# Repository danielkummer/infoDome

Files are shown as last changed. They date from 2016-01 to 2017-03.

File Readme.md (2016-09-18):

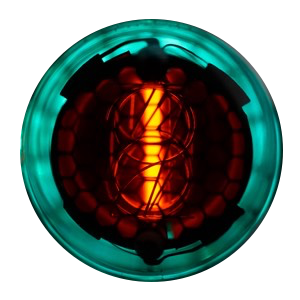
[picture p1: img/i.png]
I


# InfoDome

InfoDome Demo (http://www.youtube.com/watch?v=v8ImjMalxpY)

## Introduction

The InfoDome is an IoT project using an Arduino yùn to fetch and display remote information as well as temperature and RTC data through four [QS30-1](https://www.google.ch/search?q=QS30-1) nixie tubes.

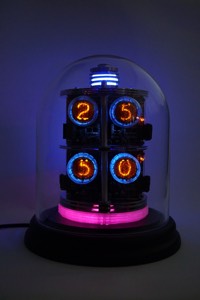
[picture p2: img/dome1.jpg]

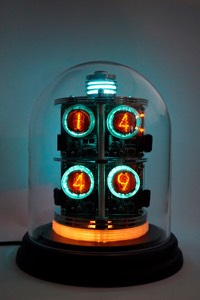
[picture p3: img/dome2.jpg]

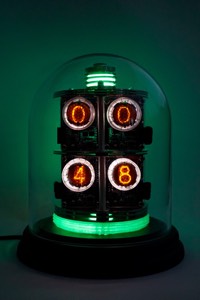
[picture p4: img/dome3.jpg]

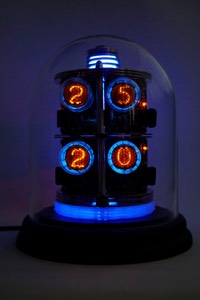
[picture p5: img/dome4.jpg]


## Features

- 7 different modes
- Distance sensor detecting :hand: movements to manually switch between the modes
- RTC Clock
- Temperature / pressure module
- WiFi
- Updates RTC time via WiFi
- Fetch remote data via WiFi

## Modes

| Number | Mode | Format | Tube Color | Light Color |
|---|---|---|---|---|
| 1 | Time | hh:mm | cyan | cyan, pulse |
| 2 | Date | mm.dd | orange | orange, pulse |
| 3 | Temperature | xx.xx' | blue | blue, pulse |
| 4 | Mail | xxxx | white | white |
| 5 | Git | xxxx | red | orange |
| 6 | Jira | xxxx | green | green |
| 7 | Cycling | - | - | rainbow |

## Configuration

The InfoDome needs to be connected to the local Wifi network. A full tutorial can be found on the official [guides page](https://www.arduino.cc/en/Guide/ArduinoYun#toc14).

Here's the short form:

 - Reset the wifi if joining a new network using the Wifi reset button:

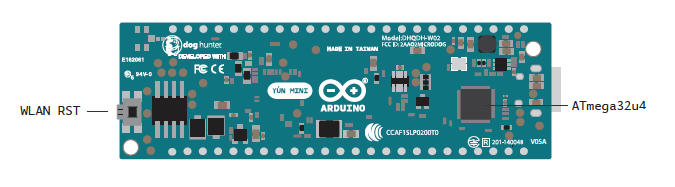
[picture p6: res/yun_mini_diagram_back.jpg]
Yun mini diagram


- Press and hold for 5 seconds until the blue WLAN led starts blinking.
- In factory reset mode, the default IP address is _192.168.240.1_
- You can now connect to the WiFi network that appears with the SSID name "Linino-XXXXXXXXXXXX" (X = MAC address)
- Enter 192.168.240.1 or "http://linino.local" in a browser.

Note that restoring the WiFi configuration will cause the reboot of the linux environment.

### Temboo Account Data

In order to authenticate against Temboo you must download your custom TembooAccount.h header file from the Temboo website and place it in the code directory.

The file contains three definitions:

```
#define TEMBOO_ACCOUNT ""
#define TEMBOO_APP_KEY_NAME ""
#define TEMBOO_APP_KEY ""
```

## Startup

The startup process takes a fair amount of time for the Yun to boot completely. During this time the dome lights are on but not animated.
After the dome is ready, it cycles through a short animation an loads the initial data, displaying 1010 while doing do. The looper mode will be set after completion.

## Operate

To switch between the modes place your hand near the infrared sensor. If the InfoDome detects it, it'll blink. The number of blinks also indicates the mode it's about to enter.

The "cycling" mode is a special mode where all other modes are automatically cycled. You can leave it by again placing your hand near the sensor.

The Dome will periodically fetch new information from Temboo. Sadly this is a blocking operation, in the meantime enjoy the digits :one::zero::one::zero:

## Other Functions

- Flash ambient light when mode changes - the number of flashes indicates the new mode
- Flash ambient light when an i2c module is malfunctioning
- Looper mode is indicated by the rainbow led on the bottom of the dome
- Data loading is indicated by the number "1010"
- Ambient light is pulsing in different modes

## Hardware

### Electronics
- [Arduino Yùn mini](http://www.arduino.org/products/boards/4-arduino-boards/arduino-yun-mini)
- 4x [A Fantastic Nixie Module for Arduino V2.0.0](http://www.play-zone.ch/en/elektronik-kit-zubehoer/avr-arduino-freeduino/zubehor/a-fantastic-nixie-module-for-arduino-arduino-compatible-v2-0-0.html)
- [Adafruit BMP085](https://www.adafruit.com/products/391) Temperature Sensor
- [Adafruit DS1307](https://www.adafruit.com/products/264) Real Time Clock
- [Sharp GP2Y0A21YK](https://www.sparkfun.com/products/242) Infrared Distance Sensor
- 3x [Ardafruit NeoPixel](https://www.adafruit.com/category/168)
- 1x Micro USB Breakout

### Other Parts

- Decorative glass tube from Interio
- Glass tube stand from Interio
- 3x old HDD
- Metal rods / screws
- 3d printed "Illuminators"

### Circuit diagram

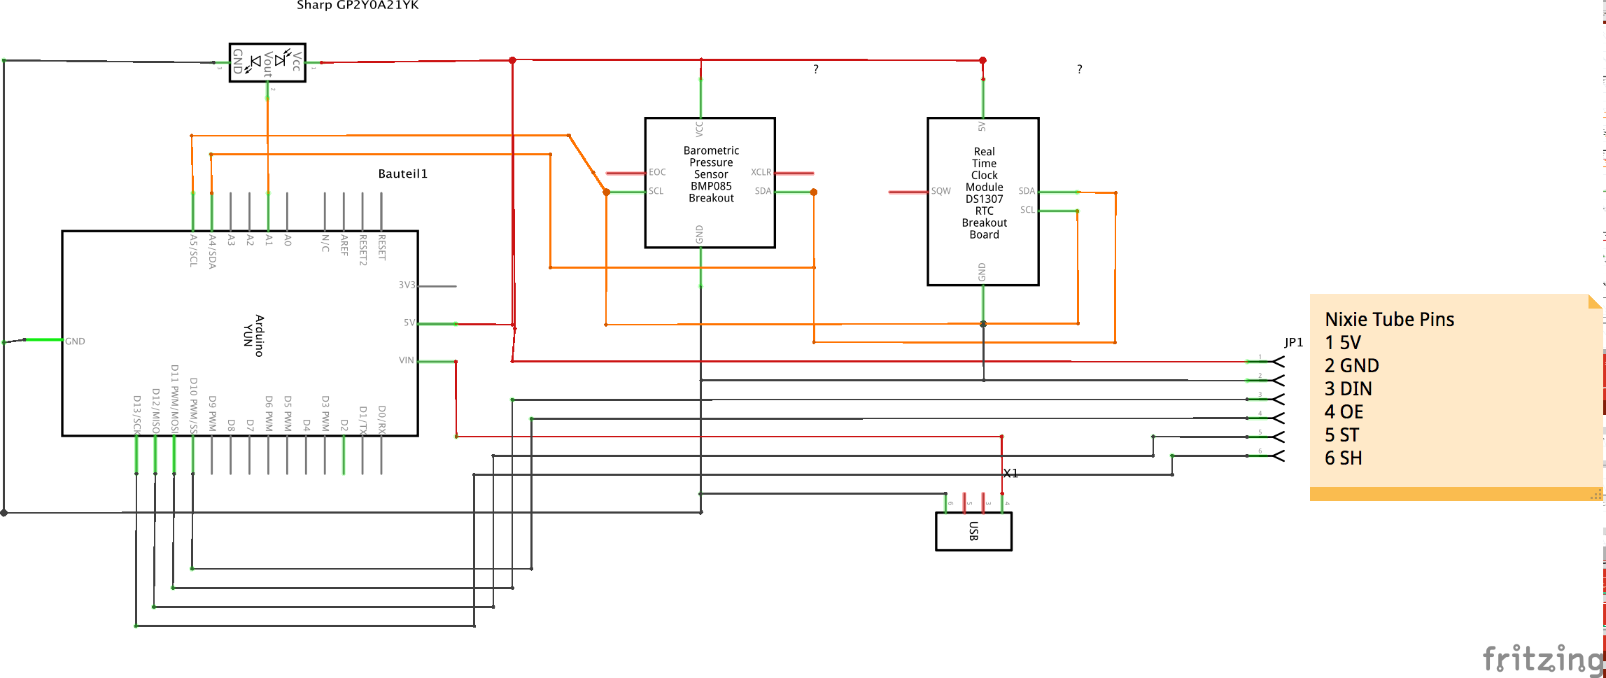
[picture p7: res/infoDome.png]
Circuit diagram


## Software

### Technical Architecture

The goal was to design a lightweight control system to operate the Dome sensors and peripherals. Because multiple operations should be done in parallel and independent of each other (read hand sensor, fade ambient lights) blocking the processor should be avoided at any cost.

The SMLib library helps to achieve this by turning the whole system into state machines which are able to execute periodically without blocking each other.

A different approach for a typical Arduino project was taken to keep the code flexible and fast.

State machines are handling data input and output. SMLib allows or _enforces_ a layered system where one machine controls the execution cycle of other machines.

Each machine serves different purposes with different execution times.

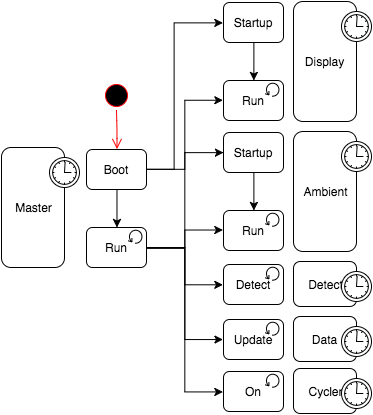
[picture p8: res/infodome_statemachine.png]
State machine


| Machine | Description |
|---|---|
| Master | Executes all other state machines and handles the booting process. |
| Display | Display values on the nixie tubes based on the current mode |
| Ambient | Control the ambient leds based on the mode |
| Detect | Detect and debounce hand movements |
| Data | Download data via WiFi from Tembo |
| Looper | If turned on, cycle to a new mode after a specific interval until turned off |

### Timers

There are several timers used to control the time machine.
By adjusting them the base operation intervals can be altered.

| Name  | Description | Value |
|---|---|---|
| BOOT_TIMEOUT | Timeout for booting animation | 5s | 
| TEMBOO_UPDATE_INTERVAL| Remote update interval | 15min |
| DETECTION_INTERVAL | Distance sensor check interval (*2) | 300ms | 
| LOOPER_INTERVAL | Looper mode timeout | 20s |
| PULSE_ON_NEW_VALUES_TIMEOUT | Tube pulse duration for new values | 4.2s |

### Online Data

The online data is aggregated using the "Choreo Editor" [Twyla](https://temboo.com/download/twyla) from the Arduino built-in IoT Stack [Temboo](https://temboo.com/).
Temboo is used in this project because it requires no additional
software in order to work - this is a good choice because the Arduino Yùn mini doesn't ship with an sd card reader, so we can't easily extend its very limited storage.

The editor takes some getting used to but is, all in all, quite easily understandable. Using the editor I've created a custom "choreo" or task which does these sequential tasks in order:

1. Fetch open merge requests from git server
2. Fetch open tickes from Atlassian Jira API
3. Fetch unread email from Google API
4. Fetch current local time for RTC adjustments

The great thing about the editor is that choreos are directly testable :smile:.

A run of this combined choreo returns:

```
    SUCCESSFUL COMPLETION:
    OUTPUT VARIABLES:

    currentTime = 19:02 16-01-03
    totalEmailCount = 45
    totalJiraTickets = 39
    totalMergeRequests = 1
```

This data can be fetched and parsed by the Arduino Temboo library.

### Libraries

- [SMLib](http://playground.arduino.cc/Code/SMlib)
- [RTCLib](https://github.com/adafruit/RTClib)
- [Adafruit BMP085](https://github.com/adafruit/Adafruit_BMP085_Unified)
- [Adafruit Sensor](https://github.com/adafruit/Adafruit_Sensor)
- Temboo (builtin)
- [NixieTube](http://www.nixieclock.org/?p=541)

# Caveats

The biggest obstacle in this project by far is the extremely limited program storage. With only 28,672 bytes (or 0.001 kbytes) the options are limited and minimal sized code is key.
The source code is currently occupying 99% program storage.
Imagine what could be done with even more space!

Because the temperature sensor is placed inside the dome, it'll read the inner temperature which will be a little over the current room temperature. We could compensate for this but it's a nice way of surveying the Dome itself.

# Closing Thoughts

As always, there are still some things left to be done... But I'm quite happy how this project turned out.

You could technically fetch and display any data you'd like to as long as it's accessible via (auhtenticated) APIs. Temboo also has a free plan with enough requests to test the choreos.

If you're an experienced :snake: (Python) programmer, there might be the option to shift the bulk of the code to the linux distribution and turn the Arduino into peripheral just displaying information.
Check the Arduino Yùn Tutorials for more information.

# Some pictures

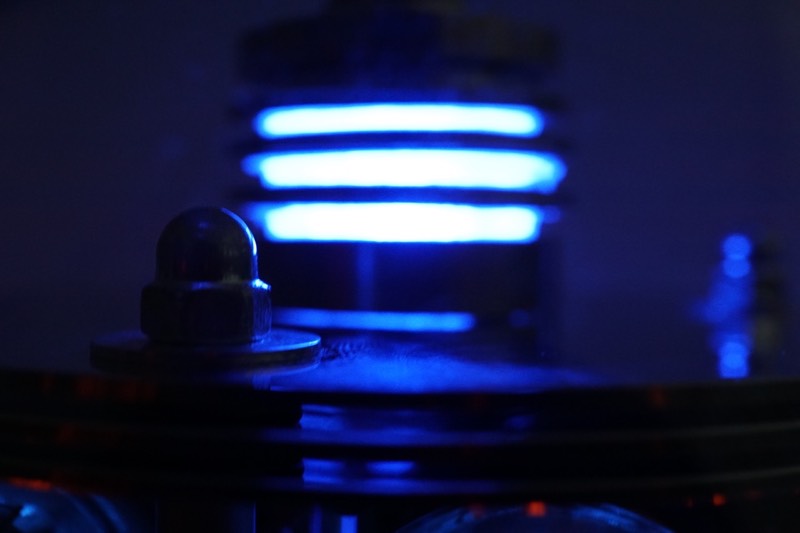
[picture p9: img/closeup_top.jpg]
Closeup top


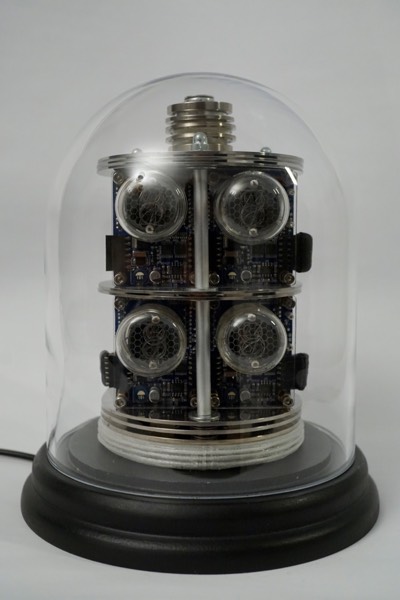
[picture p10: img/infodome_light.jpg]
Turned off


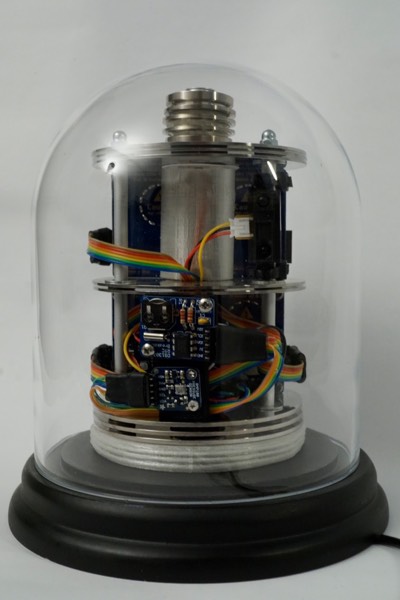
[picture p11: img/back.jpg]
Backside


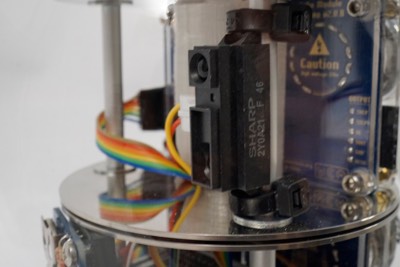
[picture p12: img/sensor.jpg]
Sensor


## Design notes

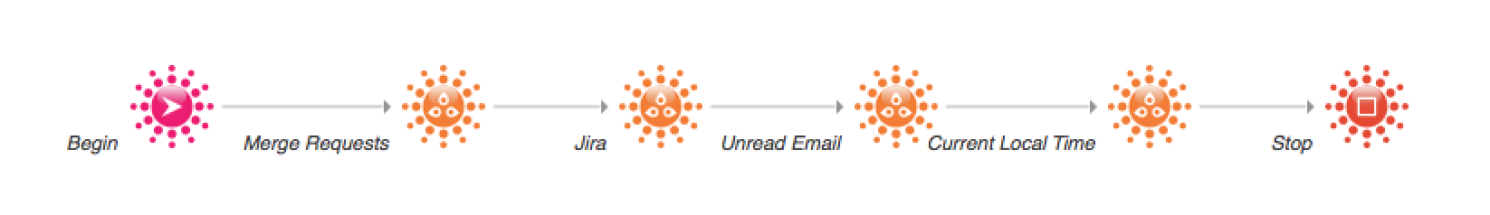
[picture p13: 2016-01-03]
res/combined_choreo.png

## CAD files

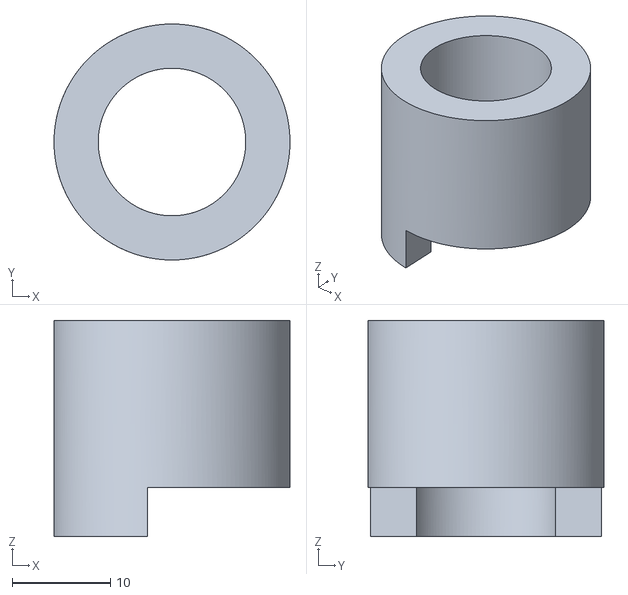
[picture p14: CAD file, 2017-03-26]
3d workfiles/complete_export.stl
24.0 x 24.0 x 22.0

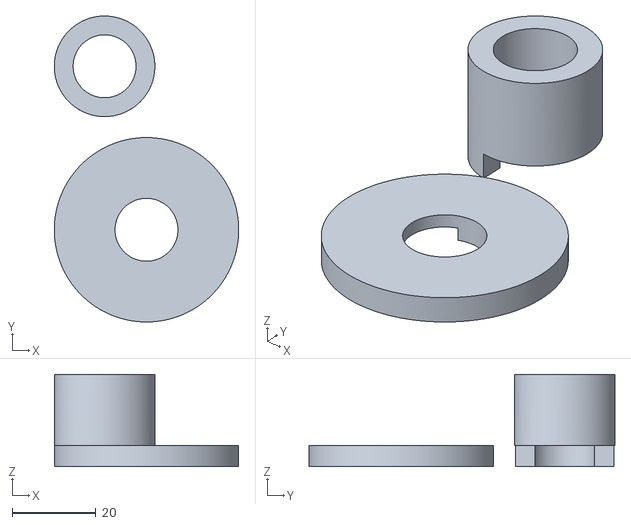
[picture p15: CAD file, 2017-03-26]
3d print/dome parts/complete_export_1.stl
44.0 x 73.0 x 22.0

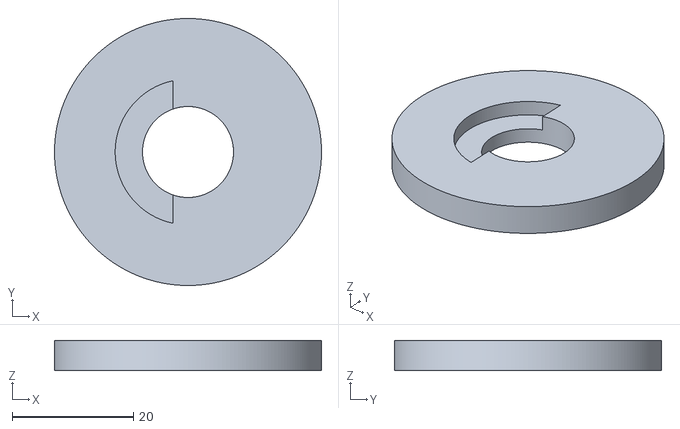
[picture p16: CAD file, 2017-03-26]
3d print/dome parts/bottom.stl
44.0 x 44.0 x 5.00

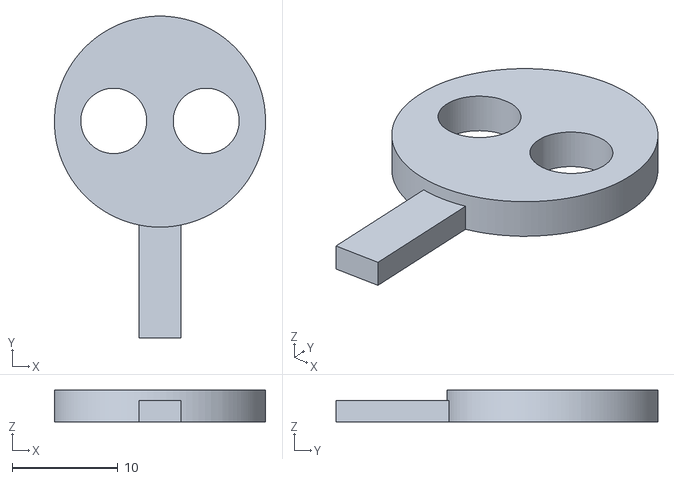
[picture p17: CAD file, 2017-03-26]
3d print/state icons/flickr_state.stl
20.0 x 30.5 x 3.00

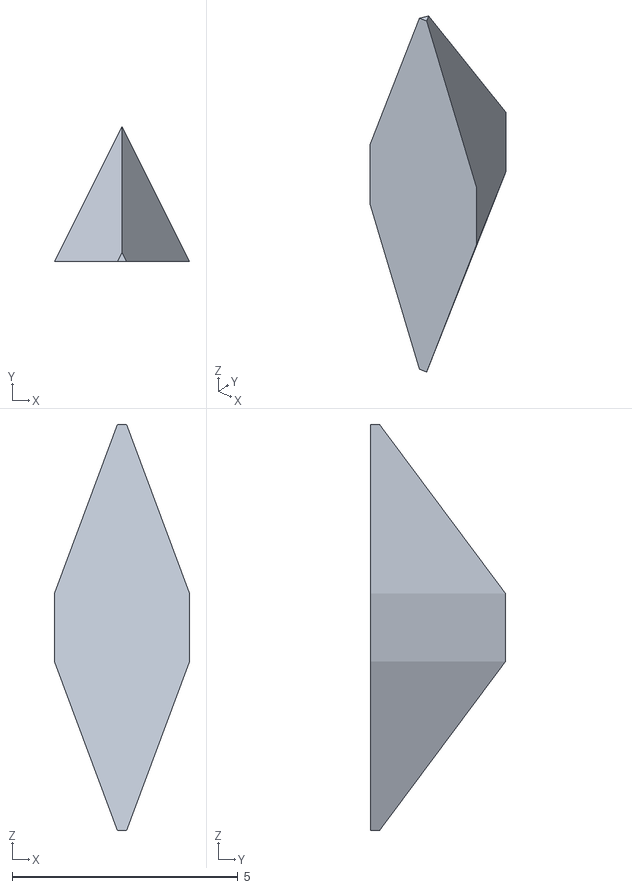
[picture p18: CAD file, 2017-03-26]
3d print/dome parts/prisma.stl
3.00 x 3.00 x 9.00

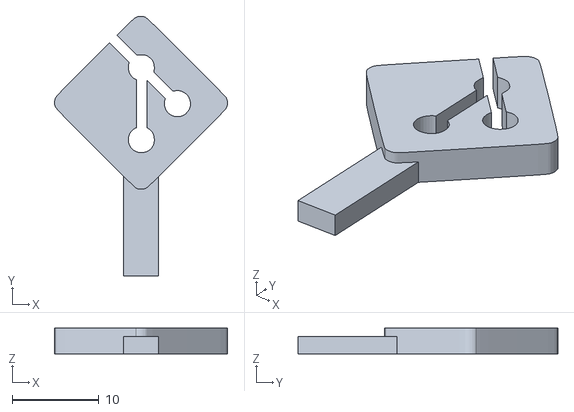
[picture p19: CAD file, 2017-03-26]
3d print/state icons/git_state.stl
20.0 x 30.0 x 3.00

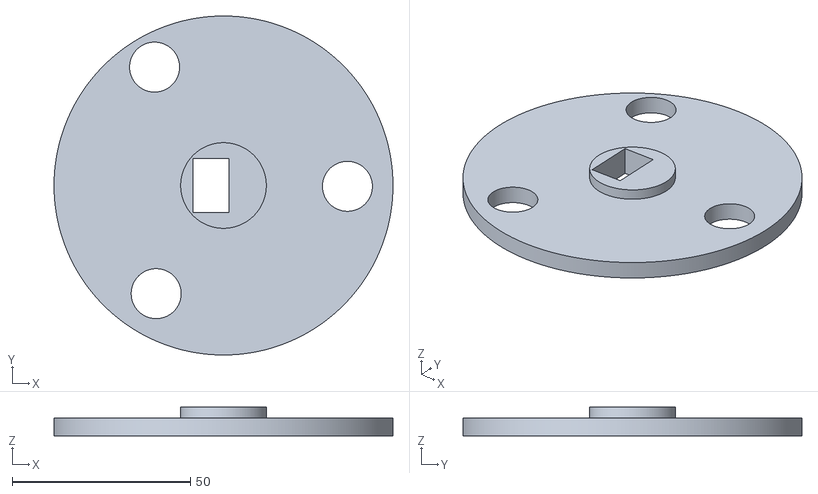
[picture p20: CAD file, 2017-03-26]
3d workfiles/newbase_holes.stl
95.0 x 95.0 x 8.00

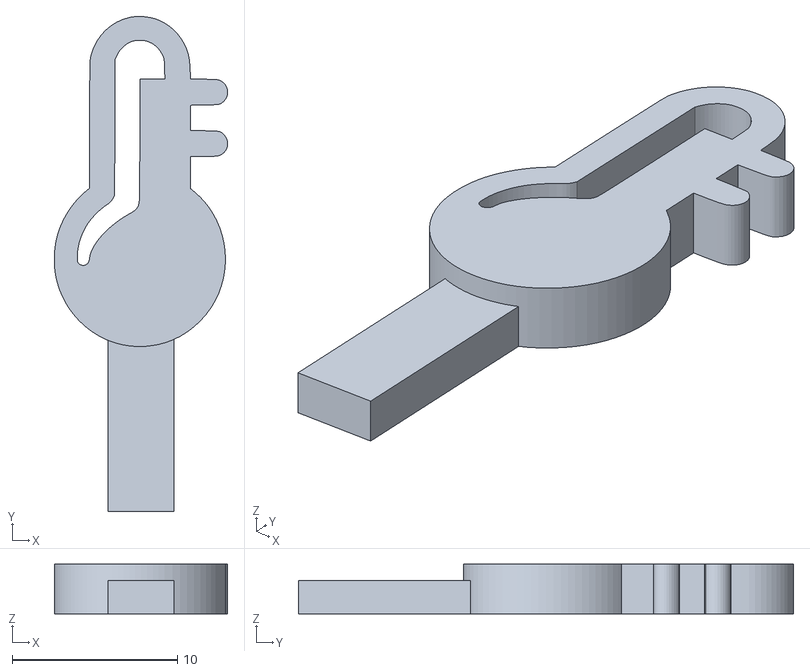
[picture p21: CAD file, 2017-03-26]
3d print/state icons/temperature_state.stl
10.5 x 30.0 x 3.00

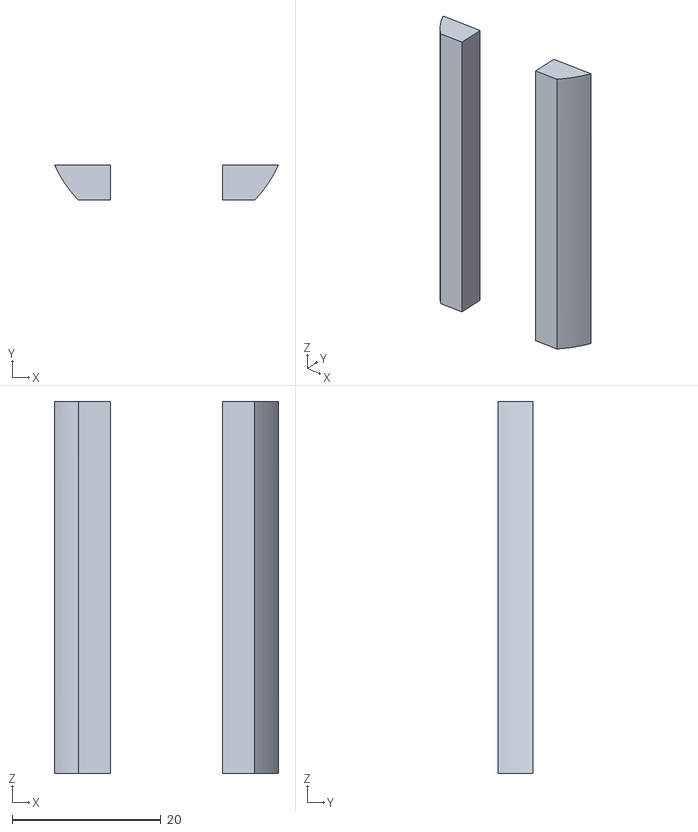
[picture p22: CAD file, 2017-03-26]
3d print/dome parts/tube_plugs.stl
30.1 x 4.75 x 50.0

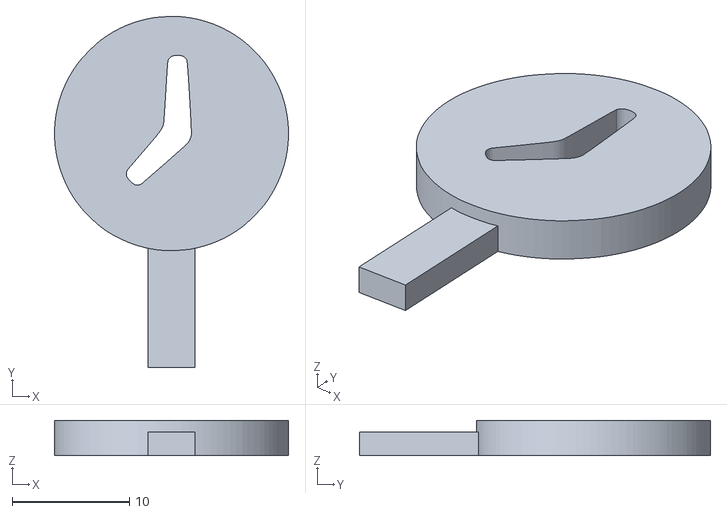
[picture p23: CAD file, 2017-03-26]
3d print/state icons/time_state.stl
20.0 x 30.0 x 3.00

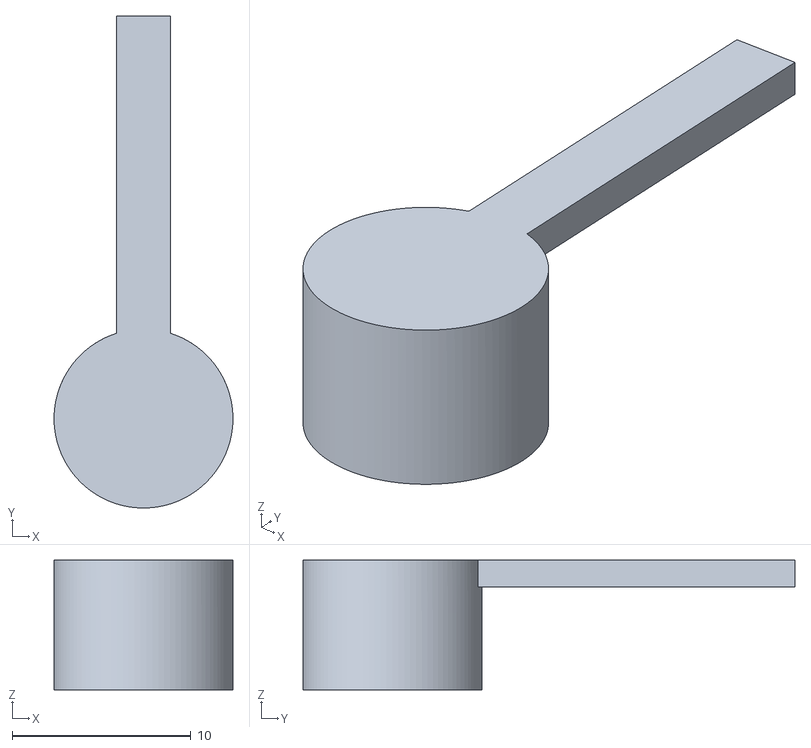
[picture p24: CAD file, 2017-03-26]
3d workfiles/hand.stl
10.0 x 27.5 x 7.25

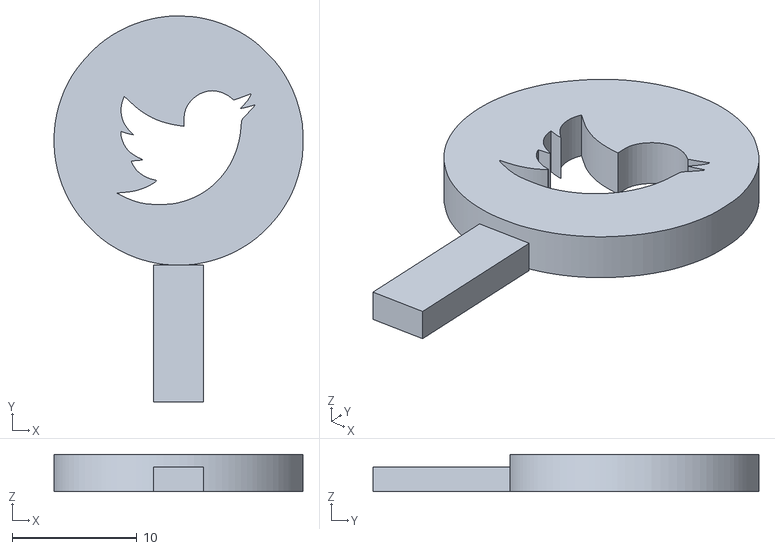
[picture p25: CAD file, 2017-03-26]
3d print/state icons/twitter_state.stl
20.0 x 31.0 x 3.00

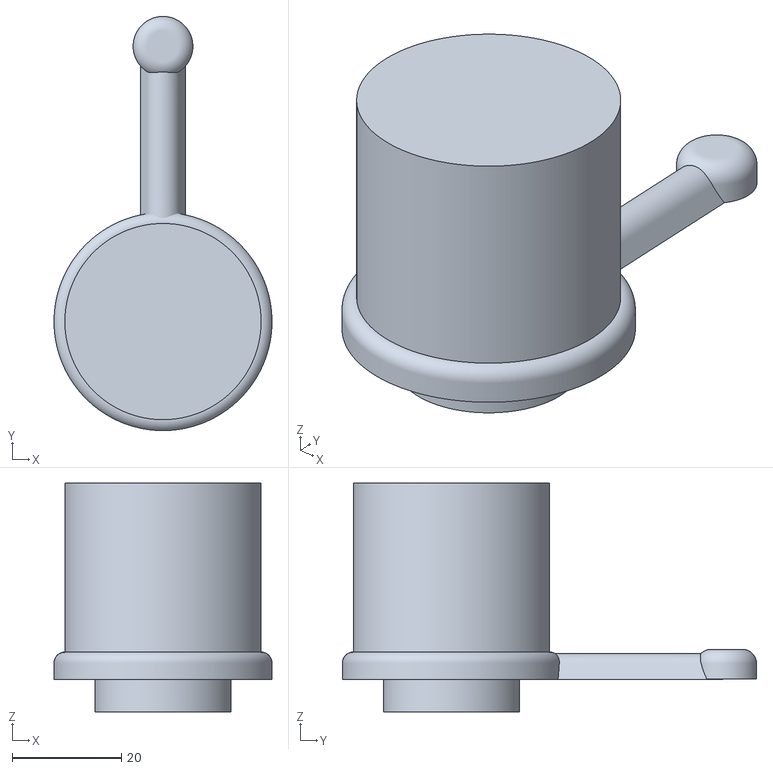
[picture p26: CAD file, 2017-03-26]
3d workfiles/newtop_test_1.stl
40.0 x 76.0 x 42.0

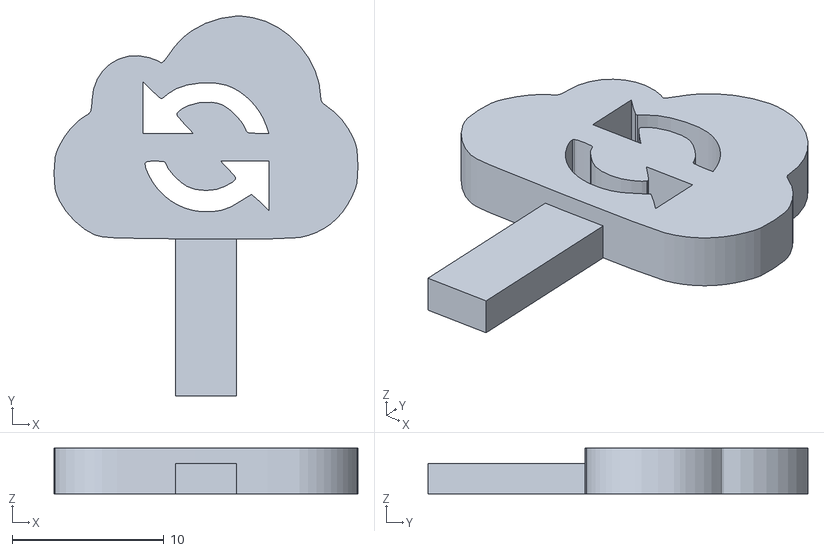
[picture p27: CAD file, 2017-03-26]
3d print/state icons/sync_state.stl
20.0 x 25.0 x 3.00

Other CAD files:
3d workfiles/clock hand.stl
3d print/state icons/email_state.stl
3d workfiles/tubewithservo.stl
3d print/state icons/Infodome States (all).stl
3d print/state icons/date_state.stl
3d print/state icons/ticket_state.stl
3d workfiles/final_tube (repaired).stl
3d workfiles/final_tube.stl
3d workfiles/middleplug.stl
3d workfiles/topplug.stl

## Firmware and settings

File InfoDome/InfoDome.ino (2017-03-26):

#include <SM.h>
#include <State.h>
#include <Adafruit_NeoPixel.h>
#include "NixieTube.h"
#include <Wire.h>
#include "RTClib.h"
#include <Adafruit_Sensor.h>
#include <Adafruit_BMP085_U.h>
#include <Bridge.h>
#include <Temboo.h>
#include "TembooAccount.h"
#include <Servo.h>


typedef struct {
  short pulse;
  uint32_t color;
} ambientSetting;

#define DETECTION_PIN                 A1
#define DETECTION_DISTANCE_THRESHOLD  380
#define NIXIE_COUNT                   4

#define TIME_MODE 0
#define DATE_MODE 1
#define TEMP_MODE 2
#define MAIL_MODE 3
#define GIT_MODE  4
#define JIRA_MODE 5
#define CYCLING_MODE 6 //all modes starting here are not part of the cycling process
#define BOOT_MODE 7

RTC_DS1307 rtc;
Adafruit_BMP085_Unified bmp = Adafruit_BMP085_Unified(10085);
Adafruit_NeoPixel strip = Adafruit_NeoPixel(3, 6, NEO_GRB + NEO_KHZ800);

NixieTube   tube = NixieTube(11, 12, 13, 10, NIXIE_COUNT); // pin_ds, pin_st. pin_sh, pin_oe, COUNT

bool i2cModulesRunning = false;
float temperature = 0.0;
short currentMode = BOOT_MODE;

short mailCount = 0;
short jiraCount = 0;
short gitCount = 0;

short lastJiraCount = -1;
short lastGitCount = -1;
short lastMailCount = -1;

bool isCycling = false;

//Prototype declarations
State DisplayStartup();
State AmbientStartup();
State DataUpdate();
State Detect();
State CyclerOn();
State Boot();


SM SMDisplay(DisplayStartup);
SM SMAmbient(AmbientStartup);
SM SMData(DataUpdate);
SM SMDetect(Detect);
SM SMCycler(CyclerOn);
SM SMMaster(Boot);

#define BOOT_TIMEOUT            5000    // finish boot state after 15 secs
#define TEMBOO_UPDATE_INTERVAL  900000L //update temboo data
#define DETECTION_INTERVAL      300     // note - detection needs to happen twice, so the actual detection happens after 2x interval
#define LOOPER_INTERVAL         20000
#define PULSE_ON_NEW_VALUES_TIMEOUT 4200

ambientSetting ambientSettings[6] = {
  {2500, strip.Color(0, 255, 128)}, // Time
  {5000, strip.Color(255, 165, 0)}, // Date
  {10000, strip.Color(0, 0, 255)},  // Temp
  {25000, strip.Color(0, 255, 0)},  // Jira
  {50000, strip.Color(255, 140, 0)},// Git
  {0, strip.Color(255, 255, 255)},  // Mail
};


Servo modeServo;  
unsigned short modeServoPosition = 0;    

//the last position is reserved for data upload and manually set in the SMData function
//unsigned short servoPositions[8] = {5, 25, 51 , 77, 102, 129, 154, 175};
unsigned short servoPositions[8] = {10, 30, 50 , 70, 90, 110, 130, 150};

void setup() {
  Bridge.begin();
  Wire.begin();

  rtc.begin();
  if (!rtc.isrunning()) {
    rtc.adjust(DateTime(F(__DATE__), F(__TIME__))); //todo set rtc by service call
  }
  tube.setBrightness(0x20); // brightness control, 0x00(off)-0xff - reduce brightness for increased lifetime
  tube.display();
  pinMode(DETECTION_PIN, INPUT);
  strip.begin();
  i2cModulesRunning = checkI2cModules();
  modeServo.attach(9);
}

void loop() {
  EXEC(SMMaster);  
}

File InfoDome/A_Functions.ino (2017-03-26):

/**
 * Check if i2c modules are up and running
 */
bool checkI2cModules() {
  return (rtc.isrunning() && bmp.begin());
}

/**
 * Set an ambient color for all leds at once
 * @param color The color to use
 */
void setAmbientColor(uint32_t color) {
  static uint32_t oldColor = 1;
  static byte j = 0;
  byte i = 0;

  //display rainbow for cycler mode in bottom led
  if (isCycling) {
    i = 1;
    strip.setPixelColor(0, Wheel((j) & 255));
    j++ % 256;
  }  
  for (i; i < strip.numPixels(); i++) {
    strip.setPixelColor(i, color);
  }
  strip.show();
}

/**
 * Blink while blocking everything else.
 *
 * @param color The color to use
 * @param times Number of times to blink
 */
void blockingAmbientBlink(uint32_t color, byte times) {
  for (byte i = 0; i < times; i++) {
    setAmbientColor(color);
    delay(150);
    setAmbientColor(strip.Color(0, 0, 0));
    delay(150);
  }
}

/**
 *  Pulse the ambient light, the pulse is linear
 *  @pulseDuration The total duration of one pulse consisting of a 50% on and a 50% off cycle
 */
void ambientPulse(unsigned short pulseDuration) {
  static unsigned short brightness = 0;
  static unsigned int elapsedDuration = 0;
  unsigned int halfDuration = pulseDuration >> 1;  

  if(elapsedDuration > pulseDuration) {
    elapsedDuration = 0;
  } else if (elapsedDuration < halfDuration ) {
    //raising
    brightness = map(elapsedDuration, 0, halfDuration, 0, 255);
  } else {
    //falling
    brightness = map(elapsedDuration, halfDuration, pulseDuration, 255, 0);
  }

  elapsedDuration += SMAmbient.Statetime(); //last enter or re-enter
  strip.setBrightness(brightness);
  strip.show();
}

/**
 * Pulse the tube light, the pulse is binary, e.g. on/off 
 * @param pulseDuration The total duration of one pulse consisting of a 50% on and a 50% off cycle
 */
void tubePulse(unsigned short pulseDuration) {
  static unsigned short brightness = 0x20;
  static unsigned int elapsedDuration = 0;
  unsigned int halfDuration = pulseDuration >> 1;  

  if(elapsedDuration > pulseDuration) {
    elapsedDuration = 0;
  } else if (elapsedDuration < halfDuration ) {
    //raising
    brightness = 0x20;
  } else {
    //falling
    brightness = 0;
  }

  elapsedDuration += SMDisplay.Statetime(); //last enter or re-enter  
  tube.setBrightness(brightness);
}

/**
 * Pulse the tubes if the values changed for a duration of 600ms.
 * Note: The oldValue pointer gets updated to newValue after the timeout period.
 * @param oldValue The old value to watch
 * @param newValue The new value
 */
void pulseTubeIfChanged(short *oldValue, short newValue) {
  static unsigned int elapsedDuration = 0;
  if(*oldValue != newValue) {      
      tubePulse(600);
      elapsedDuration += SMDisplay.Statetime();
      if(elapsedDuration > PULSE_ON_NEW_VALUES_TIMEOUT) {
        elapsedDuration = 0;
        *oldValue = newValue;
        tube.setBrightness(0x20);
      }     
  }  
}

/**
 * Colorwheel
 * Input a value 0 to 255 to get a color value.
 * The colours are a transition r - g - b - back to r.
 * @param wheelPos The position of the wheel
 */
uint32_t Wheel(byte wheelPos) {
  wheelPos = 255 - wheelPos;
  if (wheelPos < 85) {
    return strip.Color(255 - wheelPos * 3, 0, wheelPos * 3);
  }
  if (wheelPos < 170) {
    wheelPos -= 85;
    return strip.Color(0, wheelPos * 3, 255 - wheelPos * 3);
  }
  wheelPos -= 170;
  return strip.Color(wheelPos * 3, 255 - wheelPos * 3, 0);
}

/**
 * Display a rainbow, call repeatedly for each iteration
 */
void rainbow() {
  static byte j = 0;
  
  for (byte i = 0; i < strip.numPixels(); i++) {
    strip.setPixelColor(i, Wheel((i + j) & 255));
  }
  j++ % 256;
  strip.show();
}

/**
 * Get data from temboo - all data is collected running the combined choreo
 */
void getTembooData() {  
  TembooChoreo GetCombinedChoreo;

  GetCombinedChoreo.begin();
  GetCombinedChoreo.setAccountName(TEMBOO_ACCOUNT);
  GetCombinedChoreo.setAppKeyName(TEMBOO_APP_KEY_NAME);
  GetCombinedChoreo.setAppKey(TEMBOO_APP_KEY);
  GetCombinedChoreo.setChoreo(F("/Choreos/CollectedChoreos"));
  GetCombinedChoreo.run();
  while (GetCombinedChoreo.available()) {
    String name = GetCombinedChoreo.readStringUntil('\x1F');
    name.trim(); // use “trim” to get rid of newlines
    String data = GetCombinedChoreo.readStringUntil('\x1E');
    data.trim(); // use “trim” to get rid of newlines
    if (name == F("totalEmailCount")) {      
      mailCount = data.toInt();
    } else if (name == F("totalJiraTickets")) {      
      jiraCount = data.toInt();
    } else if (name == F("totalMergeRequests")) {      
      gitCount = data.toInt();
    } else if (name == F("currentTime")) {          
      updateTime(data);      
    }
  }
  GetCombinedChoreo.close();
}

/**
 * Update the rtc clock to adjust for daylight saving time
 * @param data the current date as string in the format "HH:mm yy-MM-dd"

 */
void updateTime(String data) {
  int hour = data.substring(0,2).toInt();      
  int minute = data.substring(3,2).toInt();  
  int year = data.substring(6,2).toInt();  
  int month = data.substring(9,2).toInt();  
  int day = data.substring(12,2).toInt();  
      
  DateTime now = rtc.now();

  //adjust if HH::mm or yy-MM-dd mismatch
  // the folowing addition was skipped because of size: || (now.year() != year && now.month() != month && day != now.day()) 
  if (now.hour() != hour && now.minute() != minute ) {               
    Console.println(data);
    rtc.adjust(DateTime(year, month, day, hour, minute, 0));
  }  
}

/**
 * Check if a user interaction occured. This is based on a detection threshold.
 *
 * @return bool true if threshold met or exeeded
 */
bool detect() {
  if (analogRead(DETECTION_PIN) >= DETECTION_DISTANCE_THRESHOLD) {
    return true;
  }
  return false;
}

/**
 * Display a random number and color in each tube.
 */
void displayRandomNumbers() {
  for (byte i = 0; i < NIXIE_COUNT; i++)
  {    
    tube.setBackgroundColor(i, (Color)random(0, 7));
    tube.setNumber(i, random(0, 9));
  }
  tube.display();
}

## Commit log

2016-01-03 Add project files
    [infoDome.fzz, middleplug.stl, topplug.stl]
2017-03-26 Add 3d files for 3d printing
    [Infodome States (all).stl, bottom.stl, clock hand.stl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]
2017-03-26 Optimise code
    There’s not much more to add - almost all space is used up
